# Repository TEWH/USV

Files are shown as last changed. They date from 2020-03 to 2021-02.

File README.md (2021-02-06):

Ultrasonic Vision for th Visually Impaired

At least 2.2 billion people worldwide suffer from blindness or visual impairment.1 These conditions are estimated to be four times more prevalent for low and middle income regions and the most prevalent in developing countries where conditions such as malnutrition, lack of sanitation, and inadequate health services result in a high incidence of eye disease.2 Visual impairment and blindness can be detrimental in developing countries that lack resources to integrate blind members into society. Some previous efforts to reduce the occurrence of blindness in third world countries include preventative screening programs like the eye-care services assessment tool implemented by the World Health Organization. Additionally, blindness caused by cataracts can be treated through ophthalmic surgeries, and several organizations like the Himalayan Cataract Project have corrected cataracts in over 800,000 people.3 However, fewer measures have been taken to provide wide-spread support for those who are either untreatable with cataract surgery, have chronic visual impairment, or those who are waiting to receive surgery. With our device, we aim to design a cost-effective, easy to use method for blind and visually impaired people to be able to detect the location of nearby objects. We are developing a haptic-feedback navigational system that utilizes ultrasonic sensors and a Bluetooth system.

Our device is an affordable system that consists of a belt and glasses for the detection of objects within approximately 2 m to the lower body and upper body respectively. In an effort to improve the existing condition of blindness in developing communities, our system can be used in all environments without requiring connectivity to a Wi-Fi network. As it is powered by simple batteries, it requires minimal repairs and updates, and it can be worn by virtually anyone due to its adjustable features.

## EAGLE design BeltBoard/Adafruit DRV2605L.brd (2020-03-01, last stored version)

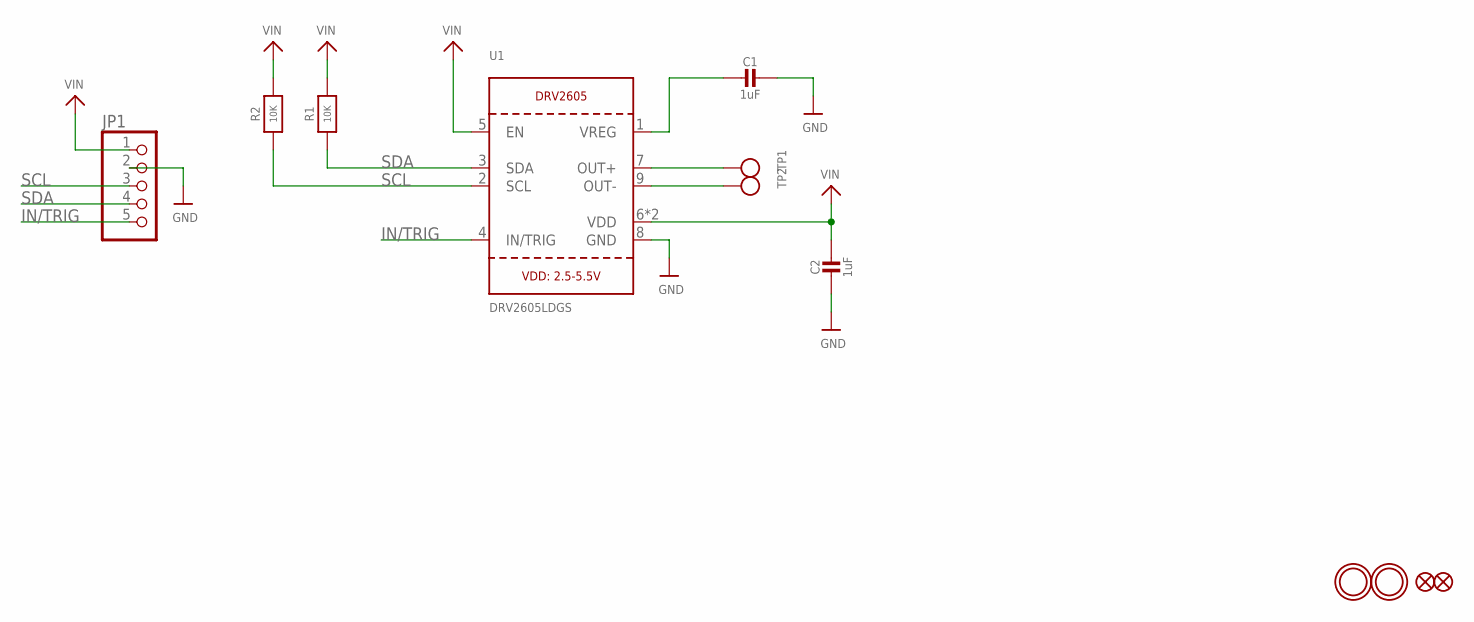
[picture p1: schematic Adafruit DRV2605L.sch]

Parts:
C1, C2: 1uF; 0805-NO
FID1, FID2: FIDUCIAL""; FIDUCIAL_1MM
JP1: HEADER-1X576MIL_FULL; 1X05_ROUND_FULL_76
R1, R2: 10K; 0805-NO
TP1, TP2: TESTPOINTPAD2MM; TESTPOINT_PAD_2MM
U1: DRV2605LDGS; PSOP10
U$2, U$3: MOUNTINGHOLE2.5; MOUNTINGHOLE_2.5_PLATED

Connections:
GND: C1.1, C2.2, JP1.2, U1.8 (GND)
IN/TRIG: JP1.5, U1.4 (IN/TRIG)
unnamed: C1.2, U1.1 (VREG)
OUT+: TP1.P$1, U1.7 (OUT+)
OUT-: TP2.P$1, U1.9 (OUT-)
SCL: JP1.3, R2.1, U1.2 (SCL)
SDA: JP1.4, R1.1, U1.3 (SDA)
VIN: C2.1, JP1.1, R1.2, R2.2, U1.5 (EN), U1.6 (VDD), U1.10 (VDD)

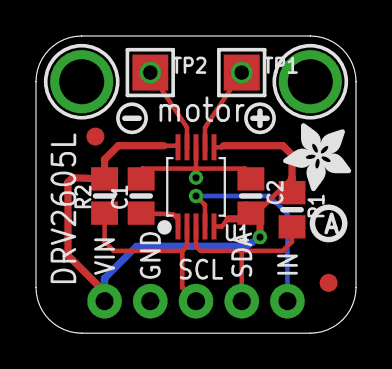
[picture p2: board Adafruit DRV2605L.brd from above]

Board: 2 copper layers, 17.8 x 16.5 mm, 16 parts (0 on the bottom side), 8 nets.

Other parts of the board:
U$4: SYMBOL_PLUS
U$5: SYMBOL_MINUS
U$15: PCBFEAT-REV-040
U$18: ADAFRUIT_3.5MM

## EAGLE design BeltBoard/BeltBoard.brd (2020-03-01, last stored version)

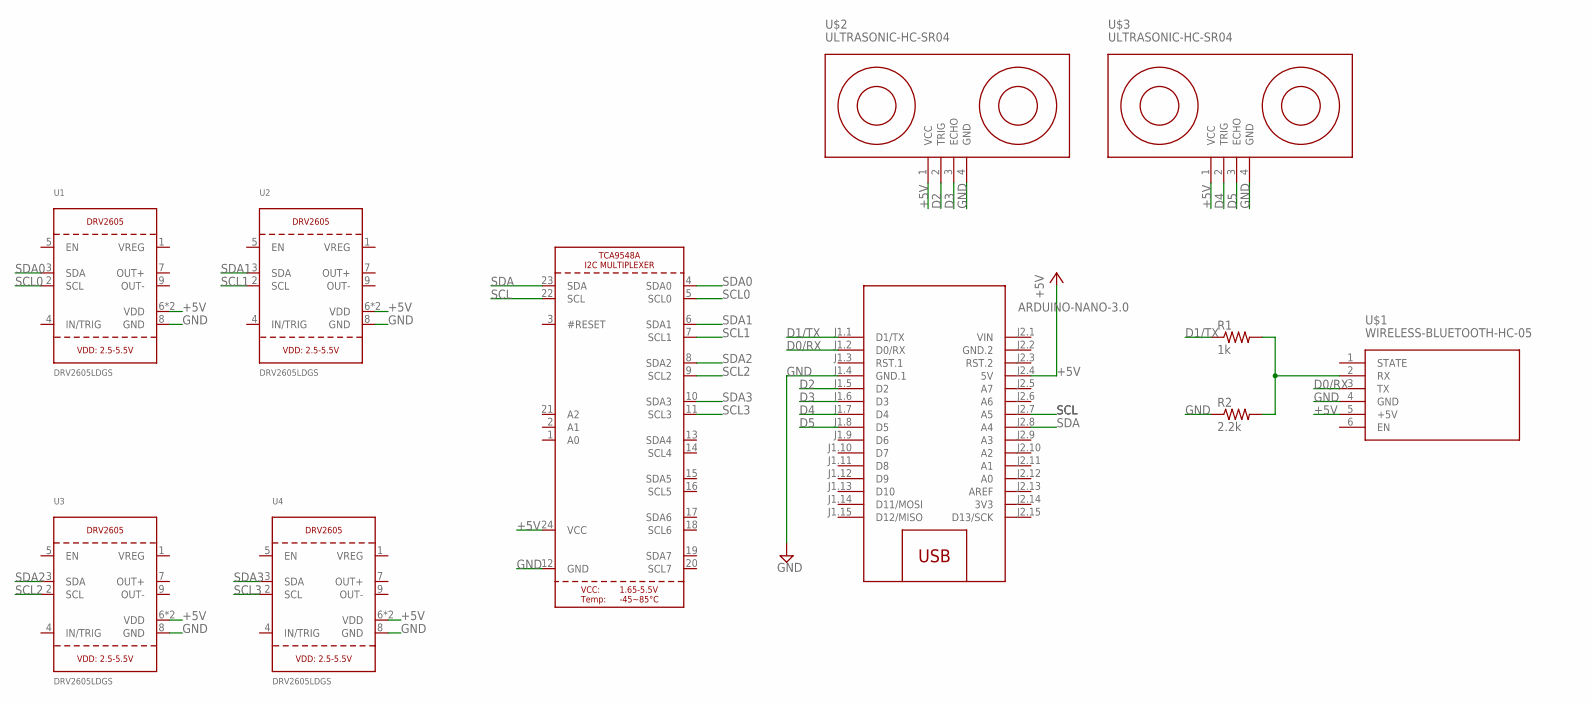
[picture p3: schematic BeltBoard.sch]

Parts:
M1: ARDUINO-NANO-3.0
R1: 1k; R0805
R2: 2.2k; R0805
U1, U2, U3, U4: DRV2605LDGS; PSOP10
U5: TCA9548APWR; TSSOP24
U$1: WIRELESS-BLUETOOTH-HC-05
U$2, U$3: ULTRASONIC-HC-SR04

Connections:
3V3: M1.J2.14 (3V3)
+5V: M1.J2.4 (5V), U1.6 (VDD), U1.10 (VDD), U2.6 (VDD), U2.10 (VDD), U3.6 (VDD), U3.10 (VDD), U4.6 (VDD), U4.10 (VDD), U5.24 (VCC), U$1.5 (+5V), U$2.1 (VCC), U$3.1 (VCC)
D0/RX: M1.J1.2 (D0/RX), U$1.3 (TX)
D1/TX: M1.J1.1 (D1/TX), R1.1
D2: M1.J1.5 (D2), U$2.2 (TRIG)
D3: M1.J1.6 (D3), U$2.3 (ECHO)
D4: M1.J1.7 (D4), U$3.2 (TRIG)
D5: M1.J1.8 (D5), U$3.3 (ECHO)
GND: M1.J1.4 (GND.1), R2.1, U1.8 (GND), U2.8 (GND), U3.8 (GND), U4.8 (GND), U5.12 (GND), U$1.4 (GND), U$2.4 (GND), U$3.4 (GND)
GND.2: M1.J2.2 (GND.2)
unnamed: R1.2, R2.2, U$1.2 (RX)
SCL: M1.J2.7 (A5), U5.22 (SCL)
SCL0: U1.2 (SCL), U5.5 (SCL0)
SCL1: U2.2 (SCL), U5.7 (SCL1)
SCL2: U3.2 (SCL), U5.9 (SCL2)
SCL3: U4.2 (SCL), U5.11 (SCL3)
SDA: M1.J2.8 (A4), U5.23 (SDA)
SDA0: U1.3 (SDA), U5.4 (SDA0)
SDA1: U2.3 (SDA), U5.6 (SDA1)
SDA2: U3.3 (SDA), U5.8 (SDA2)
SDA3: U4.3 (SDA), U5.10 (SDA3)
VIN: M1.J2.1 (VIN)

Board: 2 copper layers, 11 parts (0 on the bottom side), 19 nets, no tracks yet.

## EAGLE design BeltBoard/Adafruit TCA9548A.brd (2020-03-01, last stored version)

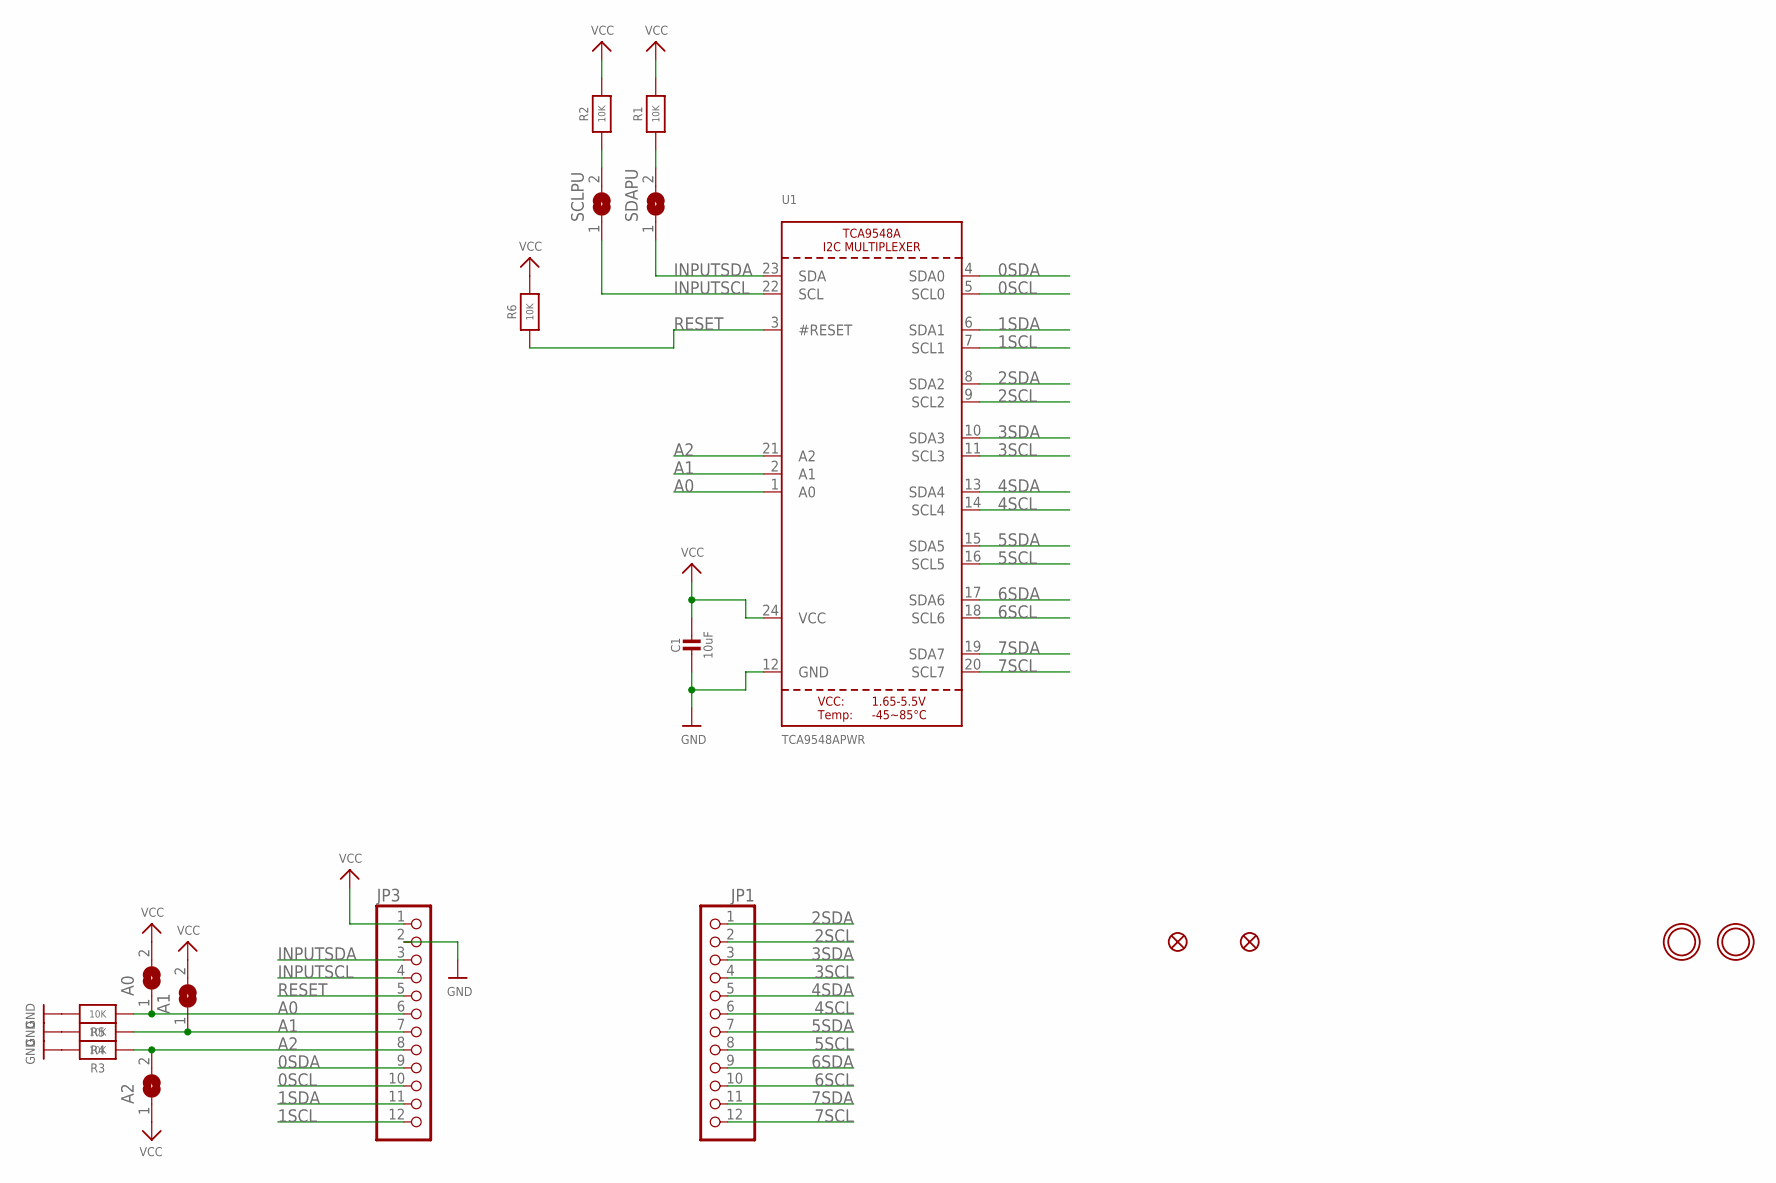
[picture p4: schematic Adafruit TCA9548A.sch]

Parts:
A0, A1, A2: SOLDERJUMPER; SOLDERJUMPER_ARROW_NOPASTE
C1: 10uF; 0805-NO
FID1, FID3: FIDUCIAL""; FIDUCIAL_1MM
JP1, JP3: HEADER-1X12; 1X12_ROUND
R1, R2, R3, R4, R5: 10K; 0805-NO
R6: 10K; _0805MP
SCLPU: SOLDERJUMPERCLOSED; SOLDERJUMPER_CLOSEDWIRE
SDAPU: SOLDERJUMPERCLOSED; SOLDERJUMPER_CLOSEDWIRE
U1: TCA9548APWR; TSSOP24
U$4, U$5: MOUNTINGHOLE2.5; MOUNTINGHOLE_2.5_PLATED

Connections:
0SCL: JP3.10, U1.5 (SCL0)
0SDA: JP3.9, U1.4 (SDA0)
1SCL: JP3.12, U1.7 (SCL1)
1SDA: JP3.11, U1.6 (SDA1)
2SCL: JP1.2, U1.9 (SCL2)
2SDA: JP1.1, U1.8 (SDA2)
3SCL: JP1.4, U1.11 (SCL3)
3SDA: JP1.3, U1.10 (SDA3)
4SCL: JP1.6, U1.14 (SCL4)
4SDA: JP1.5, U1.13 (SDA4)
5SCL: JP1.8, U1.16 (SCL5)
5SDA: JP1.7, U1.15 (SDA5)
6SCL: JP1.10, U1.18 (SCL6)
6SDA: JP1.9, U1.17 (SDA6)
7SCL: JP1.12, U1.20 (SCL7)
7SDA: JP1.11, U1.19 (SDA7)
A0: A0.1, JP3.6, R5.1, U1.1 (A0)
A1: A1.1, JP3.7, R4.1, U1.2 (A1)
A2: A2.2, JP3.8, R3.1, U1.21 (A2)
GND: C1.2, JP3.2, R3.2, R4.2, R5.2, U1.12 (GND)
INPUTSCL: JP3.4, SCLPU.1, U1.22 (SCL)
INPUTSDA: JP3.3, SDAPU.1, U1.23 (SDA)
unnamed: R2.1, SCLPU.2
unnamed: R1.1, SDAPU.2
RESET: JP3.5, R6.1, U1.3 (#RESET)
VCC: A0.2, A1.2, A2.1, C1.1, JP3.1, R1.2, R2.2, R6.2, U1.24 (VCC)

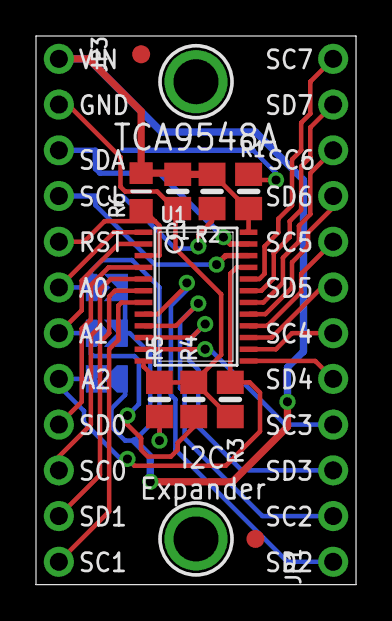
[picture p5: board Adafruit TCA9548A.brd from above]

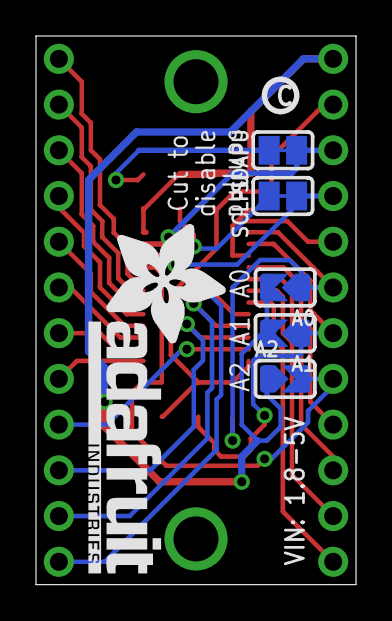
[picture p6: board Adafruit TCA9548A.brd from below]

Board: 2 copper layers, 17.8 x 30.5 mm, 21 parts (7 on the bottom side), 26 nets.

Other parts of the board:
U$6: PCBFEAT-REV-040
U$7: ADAFRUIT_TEXT_20MM

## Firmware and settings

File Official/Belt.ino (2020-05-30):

#include <Wire.h>
#include "Adafruit_DRV2605.h"
#define TCAADDR 0x70
Adafruit_DRV2605 drv1;
Adafruit_DRV2605 drv2;
Adafruit_DRV2605 drv3;
Adafruit_DRV2605 drv0;

const int trigPin3 = 9;
const int echoPin3 = 10;
float durationLeft, distanceLeft, dL;
int lim;
float leftArray[20] = {};

const int trigPin4 = 11;
const int echoPin4 = 12;
float durationRight, distanceRight, dR;
float rightArray[20] = {};


void tcaselect(uint8_t i) {
  if (i > 7) return;
 
  Wire.beginTransmission(TCAADDR);
  Wire.write(1 << i);
  Wire.endTransmission();  
}

int LR = 0;


float readLeft(){
  digitalWrite(trigPin3, LOW);
  delayMicroseconds(2);
  digitalWrite(trigPin3, HIGH);
  delayMicroseconds(10);
  digitalWrite(trigPin3, LOW);   
  durationLeft = pulseIn(echoPin3, HIGH);
  dL = (durationLeft*.0343)/2;
  return dL;
}

float readRight(){
  digitalWrite(trigPin4, LOW);
  delayMicroseconds(2);
  digitalWrite(trigPin4, HIGH);
  delayMicroseconds(10);
  digitalWrite(trigPin4, LOW);   
  durationRight = pulseIn(echoPin4, HIGH);
  dR = (durationRight*.0343)/2;
  return dR;
}

void setup() {
  pinMode(trigPin3, OUTPUT);
  pinMode(echoPin3, INPUT);

  pinMode(trigPin4, OUTPUT);
  pinMode(echoPin4, INPUT);
  drv1.begin();
  drv2.begin();
  drv3.begin();
  drv0.begin();
  
  Serial.begin(38400);
  
  
  drv1.selectLibrary(1);
  drv2.selectLibrary(1);
  drv3.selectLibrary(1);
  drv0.selectLibrary(1);

  drv1.setMode(DRV2605_MODE_INTTRIG);
  drv2.setMode(DRV2605_MODE_INTTRIG);
  drv3.setMode(DRV2605_MODE_INTTRIG);
  drv0.setMode(DRV2605_MODE_INTTRIG); 
   
  tcaselect(1);
  Wire.begin(1);
  tcaselect(2);
  Wire.begin(2);
  tcaselect(3);
  Wire.begin(3);
  tcaselect(0);
  Wire.begin(0);

  //************Calibration to ground approx. 5 seconds***************
  for (int k = 0; k < 20; k++){
    leftArray[k] = readLeft();
    rightArray[k] = readRight();
    delay(250);    
  }
  int sum = leftArray[0] + rightArray[0];
  for (int j = 1; j < 20; j++){
    sum = sum + leftArray[j] + rightArray[j]; 
  }
  lim = sum / 40;
}

void loop() {
//******************For Upper Vibration Motors*****************
  if(Serial.available() > 0) { //Detected message from master
      LR = Serial.read();
      Serial.println(LR);
      if (LR%2 == 1){
        //Serial.println(LR);
          if(LR < 10) {
            tcaselect(1);
            drv1.begin();
            drv1.setWaveform(0, 64);
            drv1.setWaveform(1,0);
            drv1.go();
        }
          else if(LR >= 10 && LR < 20) {
            tcaselect(1);
            drv1.begin();
            drv1.setWaveform(0, 65);
            drv1.setWaveform(1,0);
            drv1.go();
        }
          else if(LR >= 20 && LR < 40) {
            tcaselect(1);
            drv1.begin();
            drv1.setWaveform(0, 66);
            drv1.setWaveform(1,0);
            drv1.go();
        }
          else if(LR >= 40 && LR < 80) {
            tcaselect(1);
            drv1.begin();
            drv1.setWaveform(0, 67);
            drv1.setWaveform(1,0);
            drv1.go();
        }
          else if(LR >= 80 && LR < 140) {
            tcaselect(1);
            drv1.begin();
            drv1.setWaveform(0, 68);
            drv1.setWaveform(1,0);
            drv1.go();
        }
          else if(LR >= 140 && LR < 200) {
            tcaselect(1);
            drv1.begin();
            drv1.setWaveform(0, 69);
            drv1.setWaveform(1,0);
            drv1.go();
        }        
      }
      else{
        //Serial.println(LR);
        //Serial.print("Right:");
          if(LR < 10) {
            tcaselect(3);
            drv3.begin();
            drv3.setWaveform(0, 64);
            drv3.setWaveform(1,0);
            drv3.go();
        }
          else if(LR >= 10 && LR < 20) {
            tcaselect(3);
            drv3.begin();
            drv3.setWaveform(0, 65);
            drv3.setWaveform(1,0);
            drv3.go();
        }
          else if(LR >= 20 && LR < 40) {
            tcaselect(3);
            drv3.begin();
            drv3.setWaveform(0, 66);
            drv3.setWaveform(1,0);
            drv3.go();
        }
          else if(LR >= 40 && LR < 80) {
            tcaselect(3);
            drv3.begin();
            drv3.setWaveform(0, 67);
            drv3.setWaveform(1,0);
            drv3.go();
        }
          else if(LR >= 80 && LR < 140) {
            tcaselect(3);
            drv3.begin();
            drv3.setWaveform(0, 68);
            drv3.setWaveform(1,0);
            drv3.go();
        }
          else if(LR >= 140 && LR < 200) {
            tcaselect(3);
            drv3.begin();
            drv3.setWaveform(0, 69);
            drv3.setWaveform(1,0);
            drv3.go();
        }                    
      }          
    } 

//***************For Lower Vibration Motors & Ultrasonic Sensors on Belt****************
  int interval = (lim - 10) / 5;
  distanceLeft = readLeft();
  if (distanceLeft < 10){
          tcaselect(0);
          drv0.begin();
          drv0.setWaveform(0, 58);
          drv0.setWaveform(1,0);
          drv0.go();    
  }
  else if(distanceLeft >= 10 && distanceLeft < (lim - (4*interval))) {
          tcaselect(0);
          drv0.begin();
          drv0.setWaveform(0, 59);
          drv0.setWaveform(1,0);
          drv0.go();
  }
  else if(distanceLeft >= (lim - (4*interval)) && distanceLeft < (lim - (3*interval))) {
          tcaselect(0);
          drv0.begin();
          drv0.setWaveform(0, 60);
          drv0.setWaveform(1,0);
          drv0.go();
  }
  else if(distanceLeft >= (lim - (3*interval)) && distanceLeft < (lim - (2*interval))) {
          tcaselect(0);
          drv0.begin();
          drv0.setWaveform(0, 61);
          drv0.setWaveform(1,0);
          drv0.go();
  }
  else if(distanceLeft >= (lim - (2*interval)) && distanceLeft < (lim - interval)) {
          tcaselect(0);
          drv0.begin();
          drv0.setWaveform(0, 62);
          drv0.setWaveform(1,0);
          drv0.go();
  }
  else if(distanceLeft >= (lim - interval) && distanceLeft < lim) {
          tcaselect(0);
          drv0.begin();
          drv0.setWaveform(0, 63);
          drv0.setWaveform(1,0);
          drv0.go();
  }
  
  distanceRight = readRight();
  if (distanceRight < 10){
          tcaselect(2);
          drv2.begin();
          drv2.setWaveform(0, 58);
          drv2.setWaveform(1,0);
          drv2.go();    
  }
  else if(distanceRight >= 10 && distanceRight < (lim - (4*interval))) {
          tcaselect(2);
          drv2.begin();
          drv2.setWaveform(0, 59);
          drv2.setWaveform(1,0);
          drv2.go();
  }
  else if(distanceRight >= (lim - (4*interval)) && distanceRight < (lim - (3*interval))) {
          tcaselect(2);
          drv2.begin();
          drv2.setWaveform(0, 60);
          drv2.setWaveform(1,0);
          drv2.go();
  }
  else if(distanceRight >= (lim - (3*interval)) && distanceRight < (lim - (2*interval))) {
          tcaselect(2);
          drv2.begin();
          drv2.setWaveform(0, 61);
          drv2.setWaveform(1,0);
          drv2.go();
  }
  else if(distanceRight >= (lim - (2*interval)) && distanceRight < (lim - interval)) {
          tcaselect(2);
          drv2.begin();
          drv2.setWaveform(0, 62);
          drv2.setWaveform(1,0);
          drv2.go();
  }
  else if(distanceRight >= (lim - interval) && distanceRight < lim) {
          tcaselect(2);
          drv2.begin();
          drv2.setWaveform(0, 63);
          drv2.setWaveform(1,0);
          drv2.go();
  }  
} 

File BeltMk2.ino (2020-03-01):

#include <Wire.h>
#include "Adafruit_DRV2605.h"
#define TCAADDR 0x70
Adafruit_DRV2605 drv1;
Adafruit_DRV2605 drv2;
Adafruit_DRV2605 drv3;
Adafruit_DRV2605 drv0;


const int trigPin1 = 9;
const int echoPin1 = 10;
float duration1, distance1;

const int trigPin2 = 11;
const int echoPin2 = 12;
float duration2, distance2;

void tcaselect(uint8_t i) {
  if (i > 7) return;
 
  Wire.beginTransmission(TCAADDR);
  Wire.write(1 << i);
  Wire.endTransmission();  
}

#define ledPin 7
//uint8_t effect = 1;
int leftFlag, leftValue, rightValue = 0;
int rightFlag = 1;
void setup() {
  pinMode(trigPin1, OUTPUT);
  pinMode(echoPin1, INPUT);

  pinMode(trigPin2, OUTPUT);
  pinMode(echoPin2, INPUT);
  drv1.begin();
  drv2.begin();
  drv3.begin();
  drv0.begin();
  
  Serial.begin(38400);
  
  
  drv1.selectLibrary(1);
  drv2.selectLibrary(1);
  drv3.selectLibrary(1);
  drv0.selectLibrary(1);

  drv1.setMode(DRV2605_MODE_INTTRIG);
  drv2.setMode(DRV2605_MODE_INTTRIG);
  drv3.setMode(DRV2605_MODE_INTTRIG);
  drv0.setMode(DRV2605_MODE_INTTRIG); 
   
  tcaselect(1);
  Wire.begin(1);
  tcaselect(2);
  Wire.begin(2);
  tcaselect(3);
  Wire.begin(3);
  tcaselect(0);
  Wire.begin(0);
}
void loop() {
  if(Serial.available() > 0) { //Detected message from master
    //Serial.println("Test");
    if(leftFlag == 0 && rightFlag == 1) {
      leftValue = Serial.read();
      if(leftValue < 30) {
          tcaselect(3);
          drv3.begin();
          drv3.setWaveform(0, 64);
          drv3.setWaveform(1,0);
          drv3.go();
      }
      
      else if(leftValue > 30) {
          tcaselect(3);
          drv3.begin();
          drv3.setWaveform(0, 68);
          drv3.setWaveform(1,0);
          drv3.go();
      }
      
      Serial.print("Read left value: ");
      Serial.println(leftValue);
      leftFlag = 1;
      rightFlag = 0;
    }
    else if(rightFlag == 0 && leftFlag == 1) {
      rightValue = Serial.read();
      if(rightValue < 30) {
          tcaselect(1);
          drv1.begin();
          drv1.setWaveform(0, 64);
          drv1.setWaveform(1,0);
          drv1.go();
      }
      
      else if(rightValue > 30) {
          tcaselect(1);
          drv1.begin();
          drv1.setWaveform(0, 68);
          drv1.setWaveform(1,0);
          drv1.go();
      }

      
      Serial.print("Read right value: ");
      Serial.println(rightValue);
      leftFlag = 0;
      rightFlag = 1;    
    } 
  }
}
/*
    
  }

  digitalWrite(trigPin1, LOW);
  delayMicroseconds(2);
  digitalWrite(trigPin1, HIGH);
  delayMicroseconds(10);
  digitalWrite(trigPin1, LOW);   
  duration1 = pulseIn(echoPin1, HIGH);
  distance1 = (duration1*.0343)/2;

  if (distance1 < 20){
          tcaselect(0);
          drv0.begin();
          drv0.setWaveform(0, 64);
          drv0.setWaveform(1,0);
          drv0.go();    
    //delayMicroseconds(500);
    //delayMicroseconds(4000);
  }
  else if(distance1 > 20) {
          tcaselect(0);
          drv0.begin();
          drv0.setWaveform(0, 68);
          drv0.setWaveform(1,0);
          drv0.go();
  }
  digitalWrite(trigPin2, LOW);
  delayMicroseconds(2);
  digitalWrite(trigPin2, HIGH);
  delayMicroseconds(10);
  digitalWrite(trigPin2, LOW);   
  duration2 = pulseIn(echoPin2, HIGH);
  distance2 = (duration2*.0343)/2;

  if (distance2 < 20){
          tcaselect(2);
          drv2.begin();
          drv2.setWaveform(0, 64);
          drv2.setWaveform(1,0);
          drv2.go();    
    //delayMicroseconds(500);
    //delayMicroseconds(4000);
  }
  else if(distance2 > 20) {
          tcaselect(2);
          drv2.begin();
          drv2.setWaveform(0, 68);
          drv2.setWaveform(1,0);
          drv2.go();
  }

} 
*/

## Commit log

2020-02-23 Adding belt and goggles
2020-03-01 Adding Belt Board
    [Adafruit DRV2605L.brd, Adafruit DRV2605L.sch, Adafruit TCA9548A.brd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]
2020-05-30 Organized repo
    [Adafruit DRV2605L.brd, Adafruit DRV2605L.sch, Adafruit TCA9548A.brd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]

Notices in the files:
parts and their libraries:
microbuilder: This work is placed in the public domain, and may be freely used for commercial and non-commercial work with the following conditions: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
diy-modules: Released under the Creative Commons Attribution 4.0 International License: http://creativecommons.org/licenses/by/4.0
